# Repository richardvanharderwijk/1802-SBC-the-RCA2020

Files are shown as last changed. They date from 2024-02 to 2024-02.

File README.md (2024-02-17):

This project is the design of a small microcomputer system based on the RCA 1802 COSMAC CPU. 

The specifications of the system are:

• RCA 1802 CPU; 8 bit; up to 3,2 MHz clockspeed

• 64 kB RAM memory

• 8kBROM

• OS(ish): Utility to save, load, start programs; and examine registers and memory

• TTY serial terminal connection, software UART

• 8 bit parallel in/out

• I2C interface; and a clock/calender unit

• All signals available via connectors

• Single 5V via USB port

The design includes a PCB of 10 x 13 cm; and a build and test protocol per unit to facilitate error finding during build.

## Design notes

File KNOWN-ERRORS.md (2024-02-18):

RCA 2020 known errors

1) Error in connection U12 (pin 10, 20 switched) (First in Mk1)
Critical - Open

Switched U12 Vcc and Gnd pins (10, 20). Disadvantage of being own QC.

Workaround: swap with wires, see photo in design, build and test doc.

RfC: correct in next version

2) J5 has no opening in solder mask (First in Mk1)
Critical - Open

The connector with the three pins (J5), the supplier has delivered a wrong footpath. No opening.

Workaround: ask pcb supplier to correct (for me PCBWay’s QC flagged it and corrected it) (add both side solder mask opening for pins and make them plated)

Workaround: quick correction of gerber files without correcting in KiCad masters

RfC: correct in next version

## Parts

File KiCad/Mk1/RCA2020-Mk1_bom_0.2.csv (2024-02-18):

Component | Description | Part | References | Value | Footprint | Quantity Per PCB | Power | Datasheet
1 | Unpolarized capacitor | C | C10 | 20pF | C_Disc_D3.8mm_W2.6mm_P2.50mm | 1 |  | ~
2 | Unpolarized capacitor | C | C2 C3 | 47pF | C_Disc_D3.8mm_W2.6mm_P2.50mm | 2 |  | ~
3 | Polarized capacitor | CP | C1 | 10uF | CP_Radial_D6.3mm_P2.50mm | 1 |  | ~
4 | Polarized capacitor | CP | C4 | 1,5uF | CP_Radial_D5.0mm_P2.00mm | 1 |  | ~
5 | Polarized capacitor | CP | C5 C6 C7 C8 C9 C11 C12 C13 C14 C15 C16 | 0,22uF | CP_Radial_D5.0mm_P2.00mm | 11 |  | ~
6 | Audio Jack, 3 Poles (Stereo / TRS) | AudioJack3 | J5 | AudioJack3 | Lumberg-1501_04-MFG | 1 |  | ~
7 | Generic connector, single row, 01x40, script generated (kicad-library-utils/schlib/autogen/connector/) | Conn_01x40_Female | J1 J4 | Conn_01x40_Female | PinSocket_1x40_P2.54mm_Vertical | 2 |  | ~
8 | Generic screw terminal, single row, 01x02, script generated (kicad-library-utils/schlib/autogen/connector/) | Screw_Terminal_01x02 | J3 | Screw_Terminal_01x02 | TerminalBlock_bornier-2_P5.08mm | 1 |  | ~
9 | USB Type B connector | USB_B | J2 | USB_B | USB_B_OST_USB-B1HSxx_Horizontal | 1 |  | ~
10 | Jumper, 2-pole, closed/bridged | Jumper_2_Bridged | JP1 JP4 JP5 | Jumper_2_Bridged | PinSocket_1x02_P2.54mm_Vertical | 3 |  | ~
11 | Jumper, 2-pole, open | Jumper_2_Open | JP6 JP7 JP8 | Jumper_2_Open | PinSocket_1x02_P2.54mm_Vertical | 3 |  | ~
12 | Jumper, 3-pole, pins 1+2 closed/bridged | Jumper_3_Bridged12 | JP2 JP3 | Jumper_3_Bridged12 | PinSocket_1x03_P2.54mm_Vertical | 2 |  | ~
13 | Resistor | R | R9 R10 | 4k7 | R_Axial_DIN0207_L6.3mm_D2.5mm_P10.16mm_Horizontal | 2 | 0,010638298 | ~
14 | Resistor | R | R3 R4 R5 R6 R7 R8 R11 | 47k | R_Axial_DIN0207_L6.3mm_D2.5mm_P10.16mm_Horizontal | 7 | 0,003723404 | ~
15 | Resistor | R | R1 | 100k | R_Axial_DIN0207_L6.3mm_D2.5mm_P10.16mm_Horizontal | 1 |  | ~
16 | Resistor | R | R2 | 6,8M | R_Axial_DIN0207_L6.3mm_D2.5mm_P10.16mm_Horizontal | 1 |  | ~
17 | 4 resistor network, star topology, bussed resistors, small symbol | R_Network04 | RN1 RN2 | 4x47k | R_Array_SIP5 | 2 | 0,003723404 | http://www.vishay.com/docs/31509/csc.pdf
18 | Push button switch, generic, two pins | SW_Push | SW1 | SW_Push | RAFI_KeySwitch | 1 |  | ~
19 | Paged Parallel EEPROM 64Kb (8K x 8), DIP-28/SOIC-28 | 28C64 | U5 | 28C64 | DIP-28_W15.24mm_Socket | 1 | 0,15 | Atmel
20 | Quad Nor 2 inputs | 4001 | U3 | 4001 | DIP-14_W7.62mm_Socket | 1 |  | http://www.intersil.com/content/dam/Intersil/documents/cd40/cd4000bms-01bms-02bms-25bms.pdf
21 | Quad Nand 2 inputs | 4011 | U15 | 4011 | DIP-14_W7.62mm_Socket | 1 |  | http://www.intersil.com/content/dam/Intersil/documents/cd40/cd4011bms-12bms-23bms.pdf
22 | Triple Nand 3 inputs | 4023 | U11 | 4023 | DIP-14_W7.62mm_Socket | 1 |  | http://www.intersil.com/content/dam/Intersil/documents/cd40/cd4011bms-12bms-23bms.pdf
23 | Triple Nor 3 inputs | 4025 | U6 | 4025 | DIP-14_W7.62mm_Socket | 1 |  | http://www.intersil.com/content/dam/Intersil/documents/cd40/cd4000bms-01bms-02bms-25bms.pdf
24 | Decoder 4 to 10 lines | 4028 | U10 | 4028 | DIP-16_W7.62mm_Socket | 1 | 0,0025 | http://www.intersil.com/content/dam/Intersil/documents/cd40/cd4028bms.pdf
25 |  | 4042 | U7 U8 | 4042 | DIP-16_W7.62mm_Socket | 2
26 | Hex Buffer Inverter | 4049 | U9 | 4049 | DIP-16_W7.62mm_Socket | 1 |  | http://www.intersil.com/content/dam/intersil/documents/cd40/cd4049ubms.pdf
27 | 128K x 8 High-Speed CMOS Static RAM, 55/70ns, DIP-32/SSOP-32 | 628128_DIP32_SSOP32 | U4 | 628128_DIP32_SSOP32 | DIP-32_W15.24mm_Socket | 1 | 0,175 | http://www.futurlec.com/Datasheet/Memory/628128.pdf
28 | 8-bit Buffer/Line Driver 3-state | 74HCT244 | U12 | 74HCT244 | DIP-20_W7.62mm_Socket | 1 | 0,0025 | https://assets.nexperia.com/documents/data-sheet/74HC_HCT244.pdf
29 | 8-bit Latch 3-state outputs | 74LS573 | U13 | 74LS573 | DIP-20_W7.62mm_Socket | 1 |  | 74xx/74hc573.pdf
30 |  | 74LVC4245AD | U14 | 74LVC4245AD | SOP-24_7.5x15.4mm_P1.27mm | 1 | 0,032
31 | 8-bit, General Purpose, 5V, 3.2 MHz, DIP-40 | CDP1802ACE | U1 | CDP1802ACE | DIP-40_W15.24mm | 1 | 0,004 | http://www.cosmacelf.com/publications/data-sheets/cdp1802.pdf
32 | Positive 100mA 30V Linear Regulator, Fixed Output 3.3V, TO-92 | L78L33_TO92 | U2 | L78L33_TO92 | TO-92_Inline | 1 |  | http://www.st.com/content/ccc/resource/technical/document/datasheet/15/55/e5/aa/23/5b/43/fd/CD00000446.pdf/files/CD00000446.pdf/jcr:content/translations/en.CD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
33 |  | PCA9564PW | U16 | PCA9564PW | SO-20_12.8x7.5mm_P1.27mm | 1 | 0,0198
34 | Realtime Clock/Calendar I2C Interface, SOIC-8 | PCF8563T | U17 | PCF8563T | SOIC-8_3.9x4.9mm_P1.27mm | 1 | 0,0033 | https://assets.nexperia.com/documents/data-sheet/PCF8563.pdf
35 | Two pin crystal | Crystal | Y2 | 32.768 kHz | Crystal_Round_D3.0mm_Vertical | 1 |  | ~
36 | Two pin crystal | Crystal | Y1 | Crystal | Crystal_HC49-U_Vertical | 1 |  | ~
 |  |  |  |  |  |  | 0,407185106
Component Groups: | 36
Component Count: | 62
Fitted Components: | 62
Number of PCBs: | 1
Total components: | 62
Schematic Version: | 0.2
Schematic Date: | 20-02-2021
PCB Variant: | udefault
BoM Date: | 2021 February 22, Monday 21:50:06
Schematic Source: | RCA2020-Mk1.sch
KiCad Version: | Eeschema (5.1.5-0-10_14)

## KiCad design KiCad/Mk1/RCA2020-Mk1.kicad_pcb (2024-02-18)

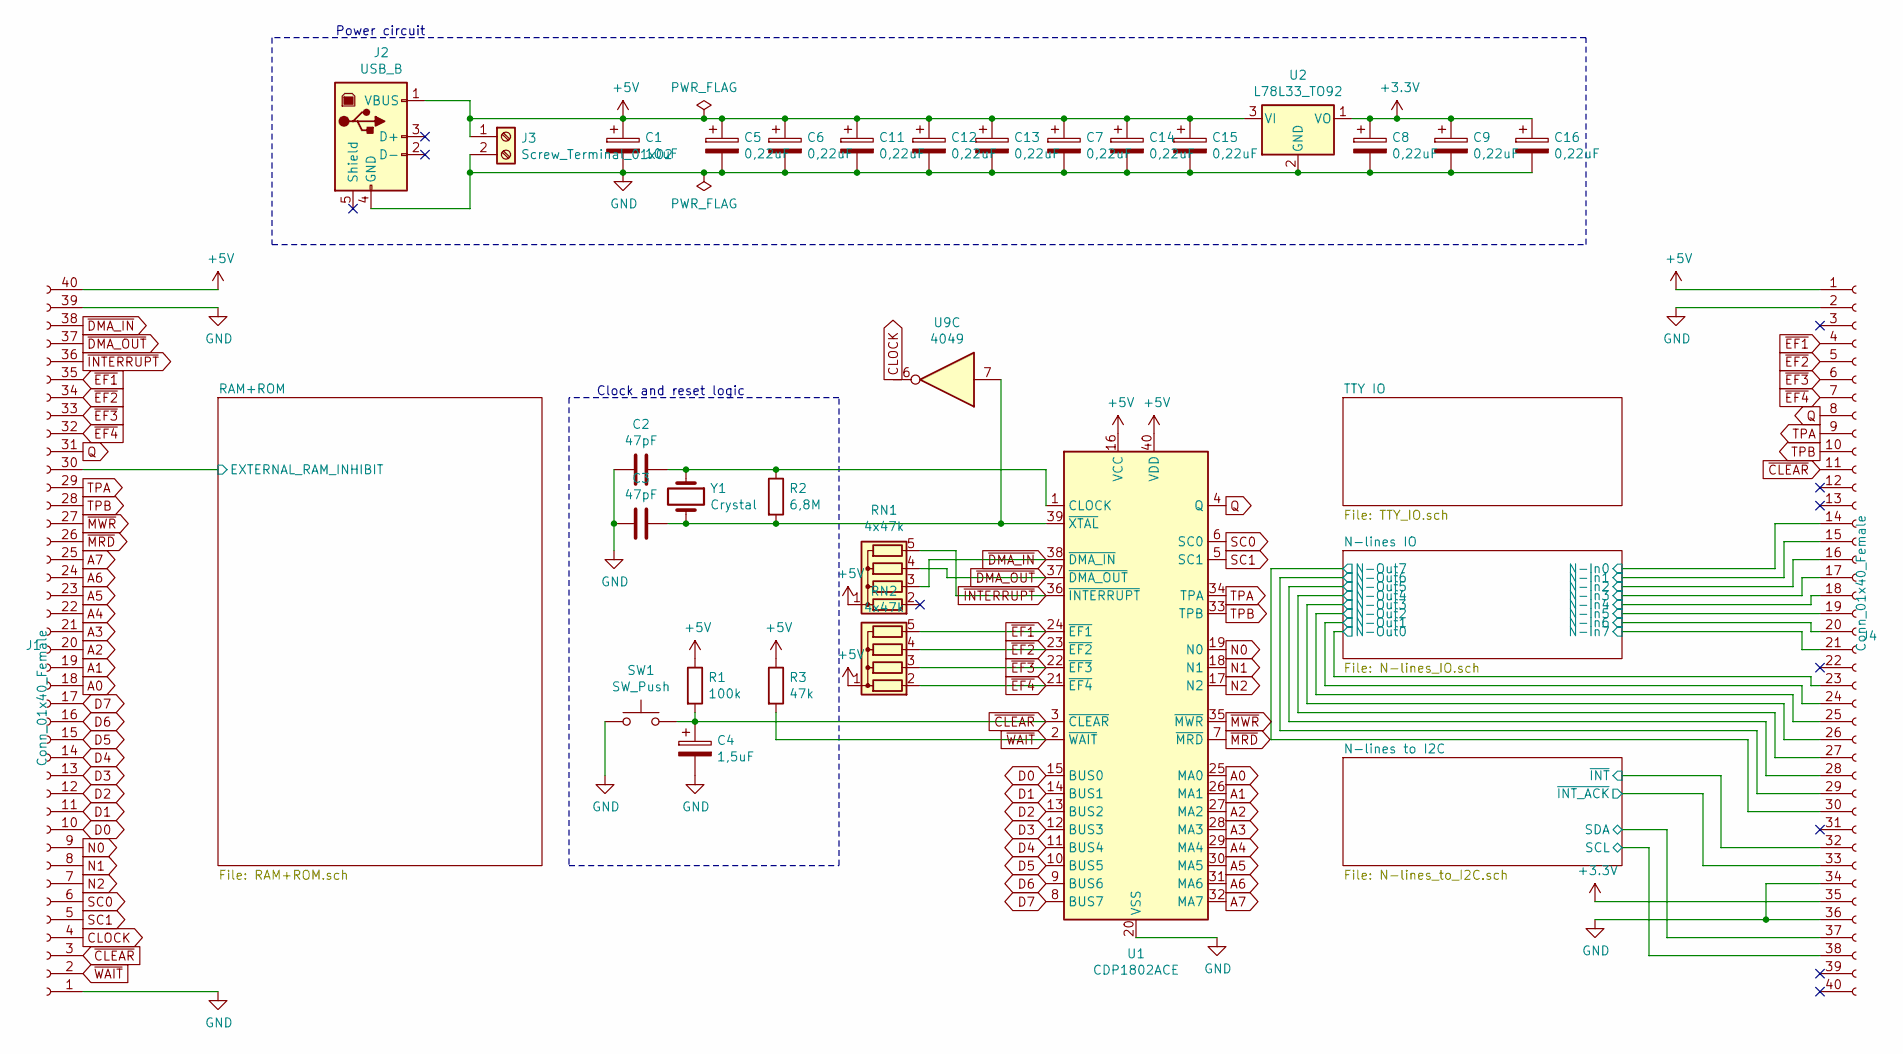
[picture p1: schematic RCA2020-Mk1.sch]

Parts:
C1: 10uF; CP_Radial_D6.3mm_P2.50mm
C2, C3: 47pF; C_Disc_D3.8mm_W2.6mm_P2.50mm
C4: 1,5uF; CP_Radial_D5.0mm_P2.00mm
C5, C6, C7, C8, C9, C11, C12, C13, C14, C15, C16: 0,22uF; CP_Radial_D5.0mm_P2.00mm
J1, J4: Conn_01x40_Female; PinSocket_1x40_P2.54mm_Vertical
J2: USB_B; USB_B_OST_USB-B1HSxx_Horizontal
J3: Screw_Terminal_01x02; TerminalBlock_bornier-2_P5.08mm
R1: 100k; R_Axial_DIN0207_L6.3mm_D2.5mm_P10.16mm_Horizontal
R2: 6,8M; R_Axial_DIN0207_L6.3mm_D2.5mm_P10.16mm_Horizontal
R3: 47k; R_Axial_DIN0207_L6.3mm_D2.5mm_P10.16mm_Horizontal
RN1, RN2: 4x47k; R_Array_SIP5
SW1: SW_Push; RAFI_KeySwitch
U1: CDP1802ACE; DIP-40_W15.24mm
U2: L78L33_TO92; TO-92_Inline
U9: 4049
Y1: Crystal; Crystal_HC49-U_Vertical

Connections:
+3V3: C8.1, C9.1, C16.1, J4.35, U2.1 (VO); also elsewhere on the board
+5V: C1.1, C5.1, C6.1, C7.1, C11.1, C12.1, C13.1, C14.1, C15.1, J1.40, J2.1 (VBUS), J3.1, J4.1, R1.1, R3.1, RN1.1 (common), RN2.1 (common), U1.16 (VCC), U1.40 (VDD), U2.3 (VI); also elsewhere on the board
/N-lines IO/N-In0: J4.14; also elsewhere on the board
/N-lines IO/N-In1: J4.15; also elsewhere on the board
/N-lines IO/N-In2: J4.16; also elsewhere on the board
/N-lines IO/N-In3: J4.17; also elsewhere on the board
/N-lines IO/N-In4: J4.18; also elsewhere on the board
/N-lines IO/N-In5: J4.19; also elsewhere on the board
/N-lines IO/N-In6: J4.20; also elsewhere on the board
/N-lines IO/N-In7: J4.21; also elsewhere on the board
/N-lines IO/N-Out0: J4.23; also elsewhere on the board
/N-lines IO/N-Out1: J4.24; also elsewhere on the board
/N-lines IO/N-Out2: J4.25; also elsewhere on the board
/N-lines IO/N-Out3: J4.26; also elsewhere on the board
/N-lines IO/N-Out4: J4.27; also elsewhere on the board
/N-lines IO/N-Out5: J4.28; also elsewhere on the board
/N-lines IO/N-Out6: J4.29; also elsewhere on the board
/N-lines IO/N-Out7: J4.30; also elsewhere on the board
/N-lines to I2C/SCL: J4.38; also elsewhere on the board
/N-lines to I2C/SDA: J4.37; also elsewhere on the board
/N-lines to I2C/~INT: J4.32; also elsewhere on the board
/N-lines to I2C/~INT_ACK: J4.33; also elsewhere on the board
/RAM+ROM/EXTERNAL_RAM_INHIBIT: J1.30; also elsewhere on the board
A0: J1.18, U1.25 (MA0); also elsewhere on the board
A1: J1.19, U1.26 (MA1); also elsewhere on the board
A2: J1.20, U1.27 (MA2); also elsewhere on the board
A3: J1.21, U1.28 (MA3); also elsewhere on the board
A4: J1.22, U1.29 (MA4); also elsewhere on the board
A5: J1.23, U1.30 (MA5); also elsewhere on the board
A6: J1.24, U1.31 (MA6); also elsewhere on the board
A7: J1.25, U1.32 (MA7); also elsewhere on the board
CLOCK: J1.4, U9.6
D0: J1.10, U1.15 (BUS0); also elsewhere on the board
D1: J1.11, U1.14 (BUS1); also elsewhere on the board
D2: J1.12, U1.13 (BUS2); also elsewhere on the board
D3: J1.13, U1.12 (BUS3); also elsewhere on the board
D4: J1.14, U1.11 (BUS4); also elsewhere on the board
D5: J1.15, U1.10 (BUS5); also elsewhere on the board
D6: J1.16, U1.9 (BUS6); also elsewhere on the board
D7: J1.17, U1.8 (BUS7); also elsewhere on the board
GND: C1.2, C2.2, C3.2, C4.2, C5.2, C6.2, C7.2, C8.2, C9.2, C11.2, C12.2, C13.2, C14.2, C15.2, C16.2, J1.1, J1.39, J2.4 (GND), J3.2, J4.2, J4.34, J4.36, SW1.1, U1.20 (VSS), U2.2 (GND); also elsewhere on the board
N0: J1.9, U1.19 (N0); also elsewhere on the board
N1: J1.8, U1.18 (N1); also elsewhere on the board
N2: J1.7, U1.17 (N2); also elsewhere on the board
unnamed: C2.1, R2.1, U1.1 (CLOCK), Y1.1
unnamed: C3.1, R2.2, U1.39 (~XTAL), U9.7, Y1.2
Q: J1.31, J4.8, U1.4 (Q); also elsewhere on the board
SC0: J1.6, U1.6 (SC0); also elsewhere on the board
SC1: J1.5, U1.5 (SC1); also elsewhere on the board
TPA: J1.29, J4.9, U1.34 (TPA); also elsewhere on the board
TPB: J1.28, J4.10, U1.33 (TPB); also elsewhere on the board
~CLEAR: C4.1, J1.3, J4.11, R1.2, SW1.2, U1.3 (~CLEAR); also elsewhere on the board
~DMA_IN: J1.38, RN1.3 (R2), U1.38 (~DMA_IN)
~DMA_OUT: J1.37, RN1.4 (R3), U1.37 (~DMA_OUT)
~EF1: J1.35, J4.4, RN2.5 (R4), U1.24 (~EF1)
~EF2: J1.34, J4.5, RN2.4 (R3), U1.23 (~EF2)
~EF3: J1.33, J4.6, RN2.3 (R2), U1.22 (~EF3)
~EF4: J1.32, J4.7, RN2.2 (R1), U1.21 (~EF4); also elsewhere on the board
~INTERRUPT: J1.36, RN1.5 (R4), U1.36 (~INTERRUPT); also elsewhere on the board
~MRD: J1.26, U1.7 (~MRD); also elsewhere on the board
~MWR: J1.27, U1.35 (~MWR); also elsewhere on the board
~WAIT: J1.2, R3.2, U1.2 (~WAIT); also elsewhere on the board

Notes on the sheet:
Clock and reset logic
Power circuit

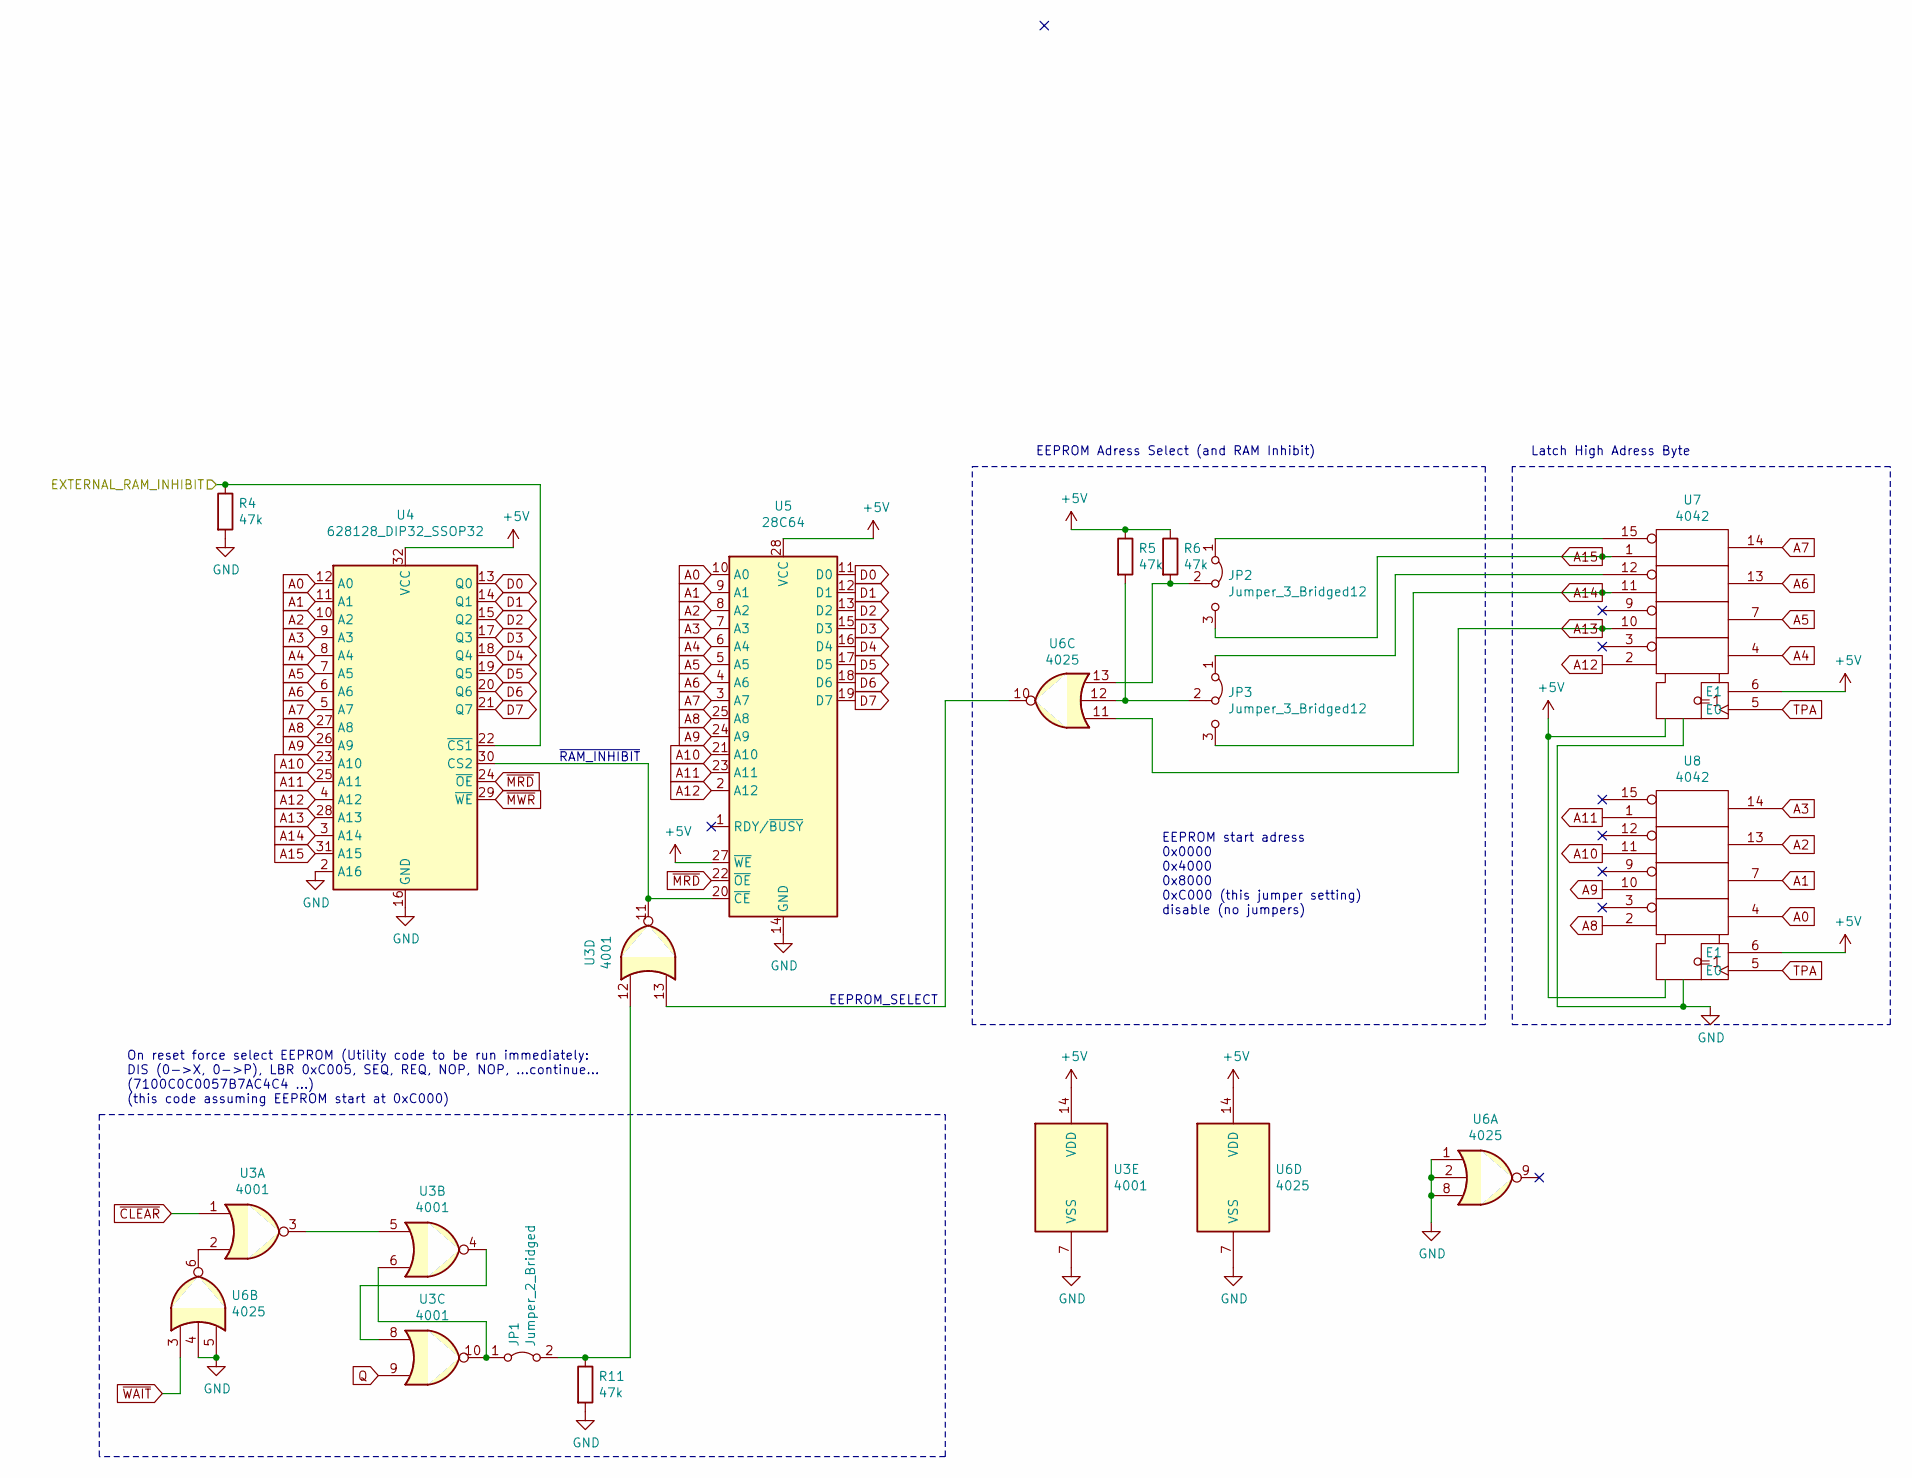
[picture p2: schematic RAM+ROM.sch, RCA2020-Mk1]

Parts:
JP1: Jumper_2_Bridged; PinSocket_1x02_P2.54mm_Vertical
JP2, JP3: Jumper_3_Bridged12; PinSocket_1x03_P2.54mm_Vertical
R4, R5, R6, R11: 47k; R_Axial_DIN0207_L6.3mm_D2.5mm_P10.16mm_Horizontal
U3: 4001; DIP-14_W7.62mm_Socket
U4: 628128_DIP32_SSOP32; DIP-32_W15.24mm_Socket
U5: 28C64; DIP-28_W15.24mm_Socket
U6: 4025; DIP-14_W7.62mm_Socket
U7, U8: 4042; DIP-16_W7.62mm_Socket

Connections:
+5V: R5.1, R6.1, U3.14 (VDD), U4.32 (VCC), U5.27 (~WE), U5.28 (VCC), U6.14 (VDD), U7.6 (E1), U7.16 (Vdd), U8.6 (E1), U8.16 (Vdd); also elsewhere on the board
/RAM+ROM/EXTERNAL_RAM_INHIBIT: R4.1, U4.22 (~CS1); also elsewhere on the board
A0: U4.12 (A0), U5.10 (A0), U8.4; also elsewhere on the board
A1: U4.11 (A1), U5.9 (A1), U8.7; also elsewhere on the board
A2: U4.10 (A2), U5.8 (A2), U8.13; also elsewhere on the board
A3: U4.9 (A3), U5.7 (A3), U8.14; also elsewhere on the board
A4: U4.8 (A4), U5.6 (A4), U7.4; also elsewhere on the board
A5: U4.7 (A5), U5.5 (A5), U7.7; also elsewhere on the board
A6: U4.6 (A6), U5.4 (A6), U7.13; also elsewhere on the board
A7: U4.5 (A7), U5.3 (A7), U7.14; also elsewhere on the board
A8: U4.27 (A8), U5.25 (A8), U8.2
A9: U4.26 (A9), U5.24 (A9), U8.10
A10: U4.23 (A10), U5.21 (A10), U8.11
A11: U4.25 (A11), U5.23 (A11), U8.1
A12: U4.4 (A12), U5.2 (A12), U7.2
A13: U4.28 (A13), U6.11, U7.10
A14: JP3.3 (B), U4.3 (A14), U7.11
A15: JP2.3 (B), U4.31 (A15), U7.1
D0: U4.13 (Q0), U5.11 (D0); also elsewhere on the board
D1: U4.14 (Q1), U5.12 (D1); also elsewhere on the board
D2: U4.15 (Q2), U5.13 (D2); also elsewhere on the board
D3: U4.17 (Q3), U5.15 (D3); also elsewhere on the board
D4: U4.18 (Q4), U5.16 (D4); also elsewhere on the board
D5: U4.19 (Q5), U5.17 (D5); also elsewhere on the board
D6: U4.20 (Q6), U5.18 (D6); also elsewhere on the board
D7: U4.21 (Q7), U5.19 (D7); also elsewhere on the board
GND: R4.2, R11.2, U3.7 (VSS), U4.2 (A16), U4.16 (GND), U5.14 (GND), U6.1, U6.2, U6.4, U6.5, U6.7 (VSS), U6.8, U7.8 (Vss), U8.8 (Vss); also elsewhere on the board
unnamed: JP1.1 (A), U3.6, U3.10
unnamed: JP1.2 (B), R11.1, U3.12
unnamed: JP2.1 (A), U7.15
unnamed: JP2.2 (C), R6.2, U6.13
unnamed: JP3.1 (A), U7.12
unnamed: JP3.2 (C), R5.2, U6.12
unnamed: U3.2, U6.6
unnamed: U3.3, U3.5
unnamed: U3.4, U3.8
unnamed: U3.11, U4.30 (CS2), U5.20 (~CE)
unnamed: U3.13, U6.10
Q: U3.9; also elsewhere on the board
TPA: U7.5 (E0), U8.5 (E0); also elsewhere on the board
~CLEAR: U3.1; also elsewhere on the board
~MRD: U4.24 (~OE), U5.22 (~OE); also elsewhere on the board
~MWR: U4.29 (~WE); also elsewhere on the board
~WAIT: U6.3; also elsewhere on the board

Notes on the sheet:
EEPROM_SELECT
~RAM_INHIBIT
Latch High Adress Byte
EEPROM Adress Select (and RAM Inhibit)
On reset force select EEPROM (Utility code to be run immediately: DIS (0->X, 0->P), LBR 0xC005, SEQ, REQ, NOP, NOP, …continue… (7100C0C0057B7AC4C4 …) (this code assuming EEPROM start at 0xC000)
EEPROM start adress 0x0000 0x4000 0x8000 0xC000 (this jumper setting) disable (no jumpers)

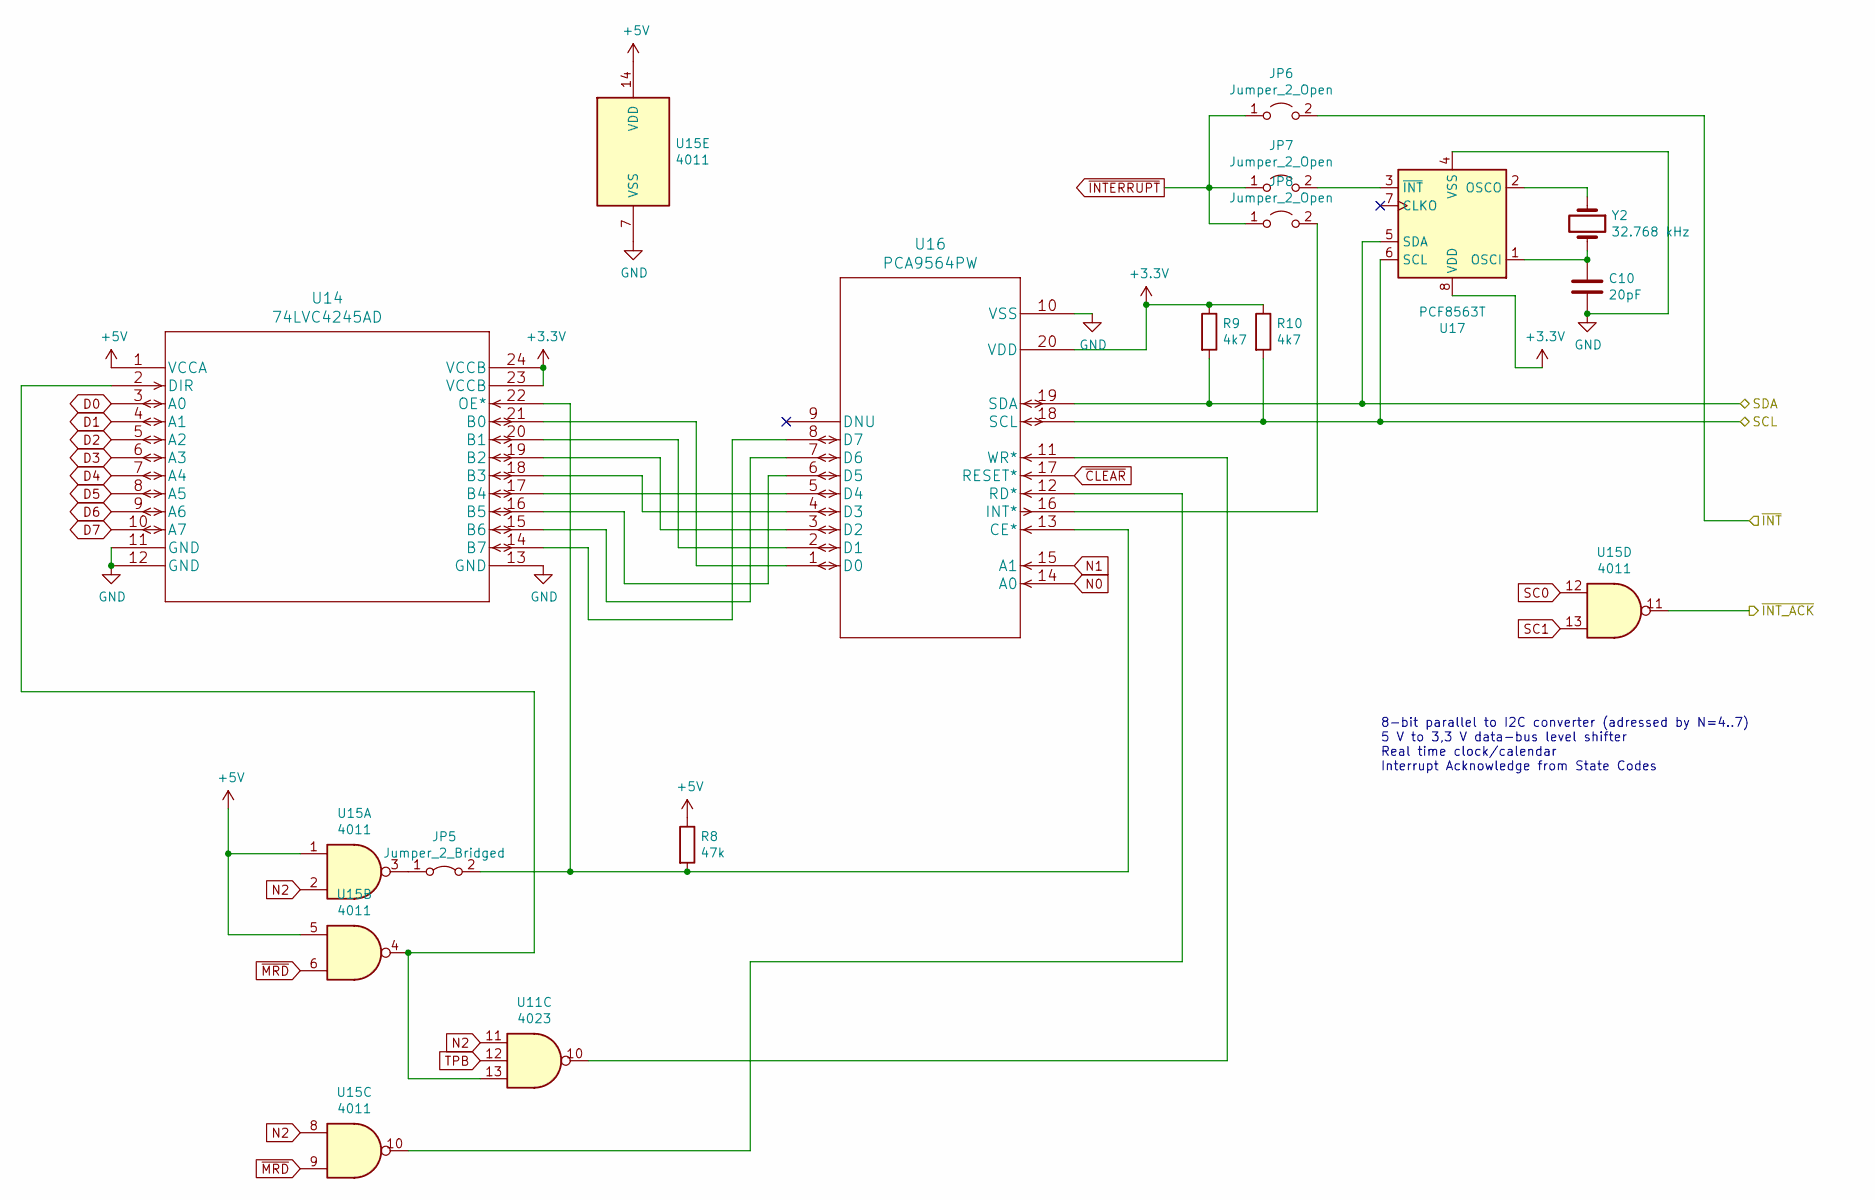
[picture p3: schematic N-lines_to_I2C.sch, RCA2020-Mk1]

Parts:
C10: 20pF; C_Disc_D3.8mm_W2.6mm_P2.50mm
JP5: Jumper_2_Bridged; PinSocket_1x02_P2.54mm_Vertical
JP6, JP7, JP8: Jumper_2_Open; PinSocket_1x02_P2.54mm_Vertical
R8: 47k; R_Axial_DIN0207_L6.3mm_D2.5mm_P10.16mm_Horizontal
R9, R10: 4k7; R_Axial_DIN0207_L6.3mm_D2.5mm_P10.16mm_Horizontal
U11: 4023; DIP-14_W7.62mm_Socket
U14: 74LVC4245AD; SOP-24_7.5x15.4mm_P1.27mm
U15: 4011; DIP-14_W7.62mm_Socket
U16: PCA9564PW; SO-20_12.8x7.5mm_P1.27mm
U17: PCF8563T; SOIC-8_3.9x4.9mm_P1.27mm
Y2: 32.768 kHz; Crystal_Round_D3.0mm_Vertical

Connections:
+3V3: R9.1, R10.1, U14.23 (VCCB), U14.24 (VCCB), U16.20 (VDD), U17.8 (VDD); also elsewhere on the board
+5V: R8.1, U14.1 (VCCA), U15.1, U15.5, U15.14 (VDD); also elsewhere on the board
/N-lines to I2C/SCL: R10.2, U16.18 (SCL), U17.6 (SCL); also elsewhere on the board
/N-lines to I2C/SDA: R9.2, U16.19 (SDA), U17.5 (SDA); also elsewhere on the board
/N-lines to I2C/~INT: JP6.2 (B); also elsewhere on the board
/N-lines to I2C/~INT_ACK: U15.11; also elsewhere on the board
D0: U14.3 (A0); also elsewhere on the board
D1: U14.4 (A1); also elsewhere on the board
D2: U14.5 (A2); also elsewhere on the board
D3: U14.6 (A3); also elsewhere on the board
D4: U14.7 (A4); also elsewhere on the board
D5: U14.8 (A5); also elsewhere on the board
D6: U14.9 (A6); also elsewhere on the board
D7: U14.10 (A7); also elsewhere on the board
GND: C10.2, U14.11 (GND), U14.12 (GND), U14.13 (GND), U15.7 (VSS), U16.10 (VSS), U17.4 (VSS); also elsewhere on the board
N0: U16.14 (A0); also elsewhere on the board
N1: U16.15 (A1); also elsewhere on the board
N2: U11.11, U15.2, U15.8; also elsewhere on the board
unnamed: C10.1, U17.1 (OSCI), Y2.2
unnamed: JP5.1 (A), U15.3
unnamed: JP5.2 (B), R8.2, U14.22 (OE*), U16.13 (CE*)
unnamed: JP7.2 (B), U17.3 (~INT~)
unnamed: JP8.2 (B), U16.16 (INT*)
unnamed: U11.10, U16.11 (WR*)
unnamed: U11.13, U14.2 (DIR), U15.4
unnamed: U14.14 (B7), U16.8 (D7)
unnamed: U14.15 (B6), U16.7 (D6)
unnamed: U14.16 (B5), U16.6 (D5)
unnamed: U14.17 (B4), U16.5 (D4)
unnamed: U14.18 (B3), U16.4 (D3)
unnamed: U14.19 (B2), U16.3 (D2)
unnamed: U14.20 (B1), U16.2 (D1)
unnamed: U14.21 (B0), U16.1 (D0)
unnamed: U15.10, U16.12 (RD*)
unnamed: U17.2 (OSCO), Y2.1
SC0: U15.12; also elsewhere on the board
SC1: U15.13; also elsewhere on the board
TPB: U11.12; also elsewhere on the board
~CLEAR: U16.17 (RESET*); also elsewhere on the board
~INTERRUPT: JP6.1 (A), JP7.1 (A), JP8.1 (A); also elsewhere on the board
~MRD: U15.6, U15.9; also elsewhere on the board

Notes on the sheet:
8-bit parallel to I2C converter (adressed by N=4..7) 5 V to 3,3 V data-bus level shifter Real time clock/calendar Interrupt Acknowledge from State Codes

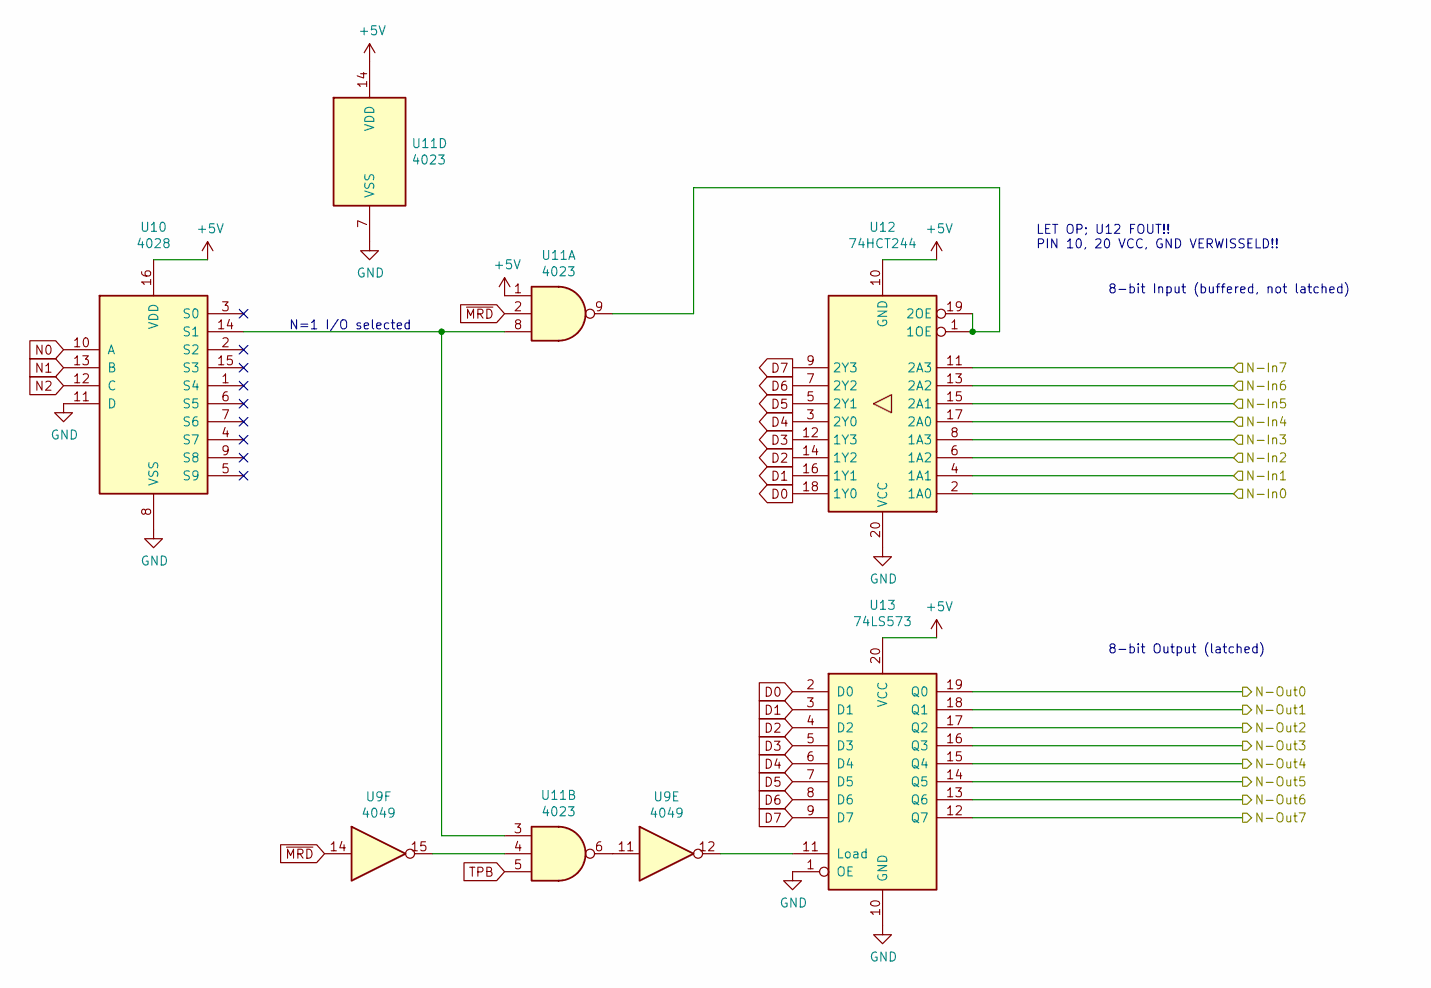
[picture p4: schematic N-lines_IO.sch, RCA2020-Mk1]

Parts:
U9: 4049; DIP-16_W7.62mm_Socket
U10: 4028; DIP-16_W7.62mm_Socket
U11: 4023; DIP-14_W7.62mm_Socket
U12: 74HCT244; DIP-20_W7.62mm_Socket
U13: 74LS573; DIP-20_W7.62mm_Socket

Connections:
+5V: U10.16 (VDD), U11.1, U11.14 (VDD), U12.10 (GND), U13.20 (VCC); also elsewhere on the board
/N-lines IO/N-In0: U12.2 (1A0); also elsewhere on the board
/N-lines IO/N-In1: U12.4 (1A1); also elsewhere on the board
/N-lines IO/N-In2: U12.6 (1A2); also elsewhere on the board
/N-lines IO/N-In3: U12.8 (1A3); also elsewhere on the board
/N-lines IO/N-In4: U12.17 (2A0); also elsewhere on the board
/N-lines IO/N-In5: U12.15 (2A1); also elsewhere on the board
/N-lines IO/N-In6: U12.13 (2A2); also elsewhere on the board
/N-lines IO/N-In7: U12.11 (2A3); also elsewhere on the board
/N-lines IO/N-Out0: U13.19 (Q0); also elsewhere on the board
/N-lines IO/N-Out1: U13.18 (Q1); also elsewhere on the board
/N-lines IO/N-Out2: U13.17 (Q2); also elsewhere on the board
/N-lines IO/N-Out3: U13.16 (Q3); also elsewhere on the board
/N-lines IO/N-Out4: U13.15 (Q4); also elsewhere on the board
/N-lines IO/N-Out5: U13.14 (Q5); also elsewhere on the board
/N-lines IO/N-Out6: U13.13 (Q6); also elsewhere on the board
/N-lines IO/N-Out7: U13.12 (Q7); also elsewhere on the board
D0: U12.18 (1Y0), U13.2 (D0); also elsewhere on the board
D1: U12.16 (1Y1), U13.3 (D1); also elsewhere on the board
D2: U12.14 (1Y2), U13.4 (D2); also elsewhere on the board
D3: U12.12 (1Y3), U13.5 (D3); also elsewhere on the board
D4: U12.3 (2Y0), U13.6 (D4); also elsewhere on the board
D5: U12.5 (2Y1), U13.7 (D5); also elsewhere on the board
D6: U12.7 (2Y2), U13.8 (D6); also elsewhere on the board
D7: U12.9 (2Y3), U13.9 (D7); also elsewhere on the board
GND: U10.8 (VSS), U10.11 (D), U11.7 (VSS), U12.20 (VCC), U13.1 (OE), U13.10 (GND); also elsewhere on the board
N0: U10.10 (A); also elsewhere on the board
N1: U10.13 (B); also elsewhere on the board
N2: U10.12 (C); also elsewhere on the board
unnamed: U10.14 (S1), U11.3, U11.8
unnamed: U9.15, U11.4
unnamed: U9.11, U11.6
unnamed: U11.9, U12.1 (1OE), U12.19 (2OE)
unnamed: U9.12, U13.11 (Load)
TPB: U11.5; also elsewhere on the board
~MRD: U9.14, U11.2; also elsewhere on the board

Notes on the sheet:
8-bit Input (buffered, not latched)
8-bit Output (latched)
N=1 I/O selected
LET OP; U12 FOUT!! PIN 10, 20 VCC, GND VERWISSELD!!

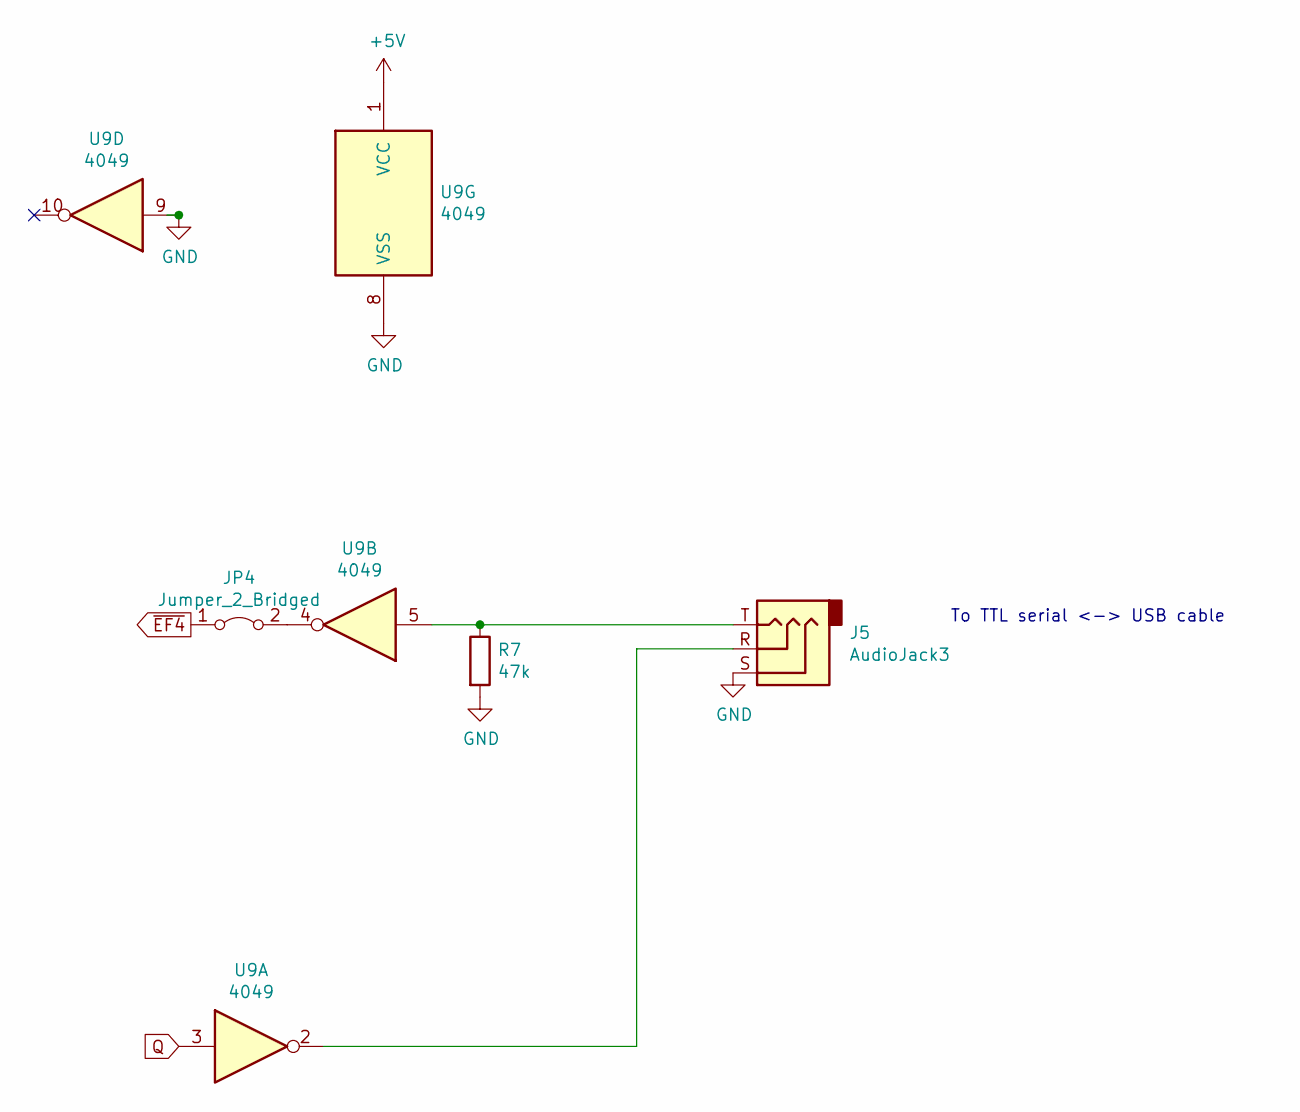
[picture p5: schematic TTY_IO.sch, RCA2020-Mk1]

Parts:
J5: AudioJack3; Lumberg-1501_04-MFG
JP4: Jumper_2_Bridged; PinSocket_1x02_P2.54mm_Vertical
R7: 47k; R_Axial_DIN0207_L6.3mm_D2.5mm_P10.16mm_Horizontal
U9: 4049; DIP-16_W7.62mm_Socket

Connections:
+5V: U9.1 (VCC); also elsewhere on the board
GND: J5.S, R7.2, U9.8 (VSS), U9.9; also elsewhere on the board
unnamed: J5.R, U9.2
unnamed: J5.T, R7.1, U9.5
unnamed: JP4.2 (B), U9.4
Q: U9.3; also elsewhere on the board
~EF4: JP4.1 (A); also elsewhere on the board

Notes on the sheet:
To TTL serial <-> USB cable

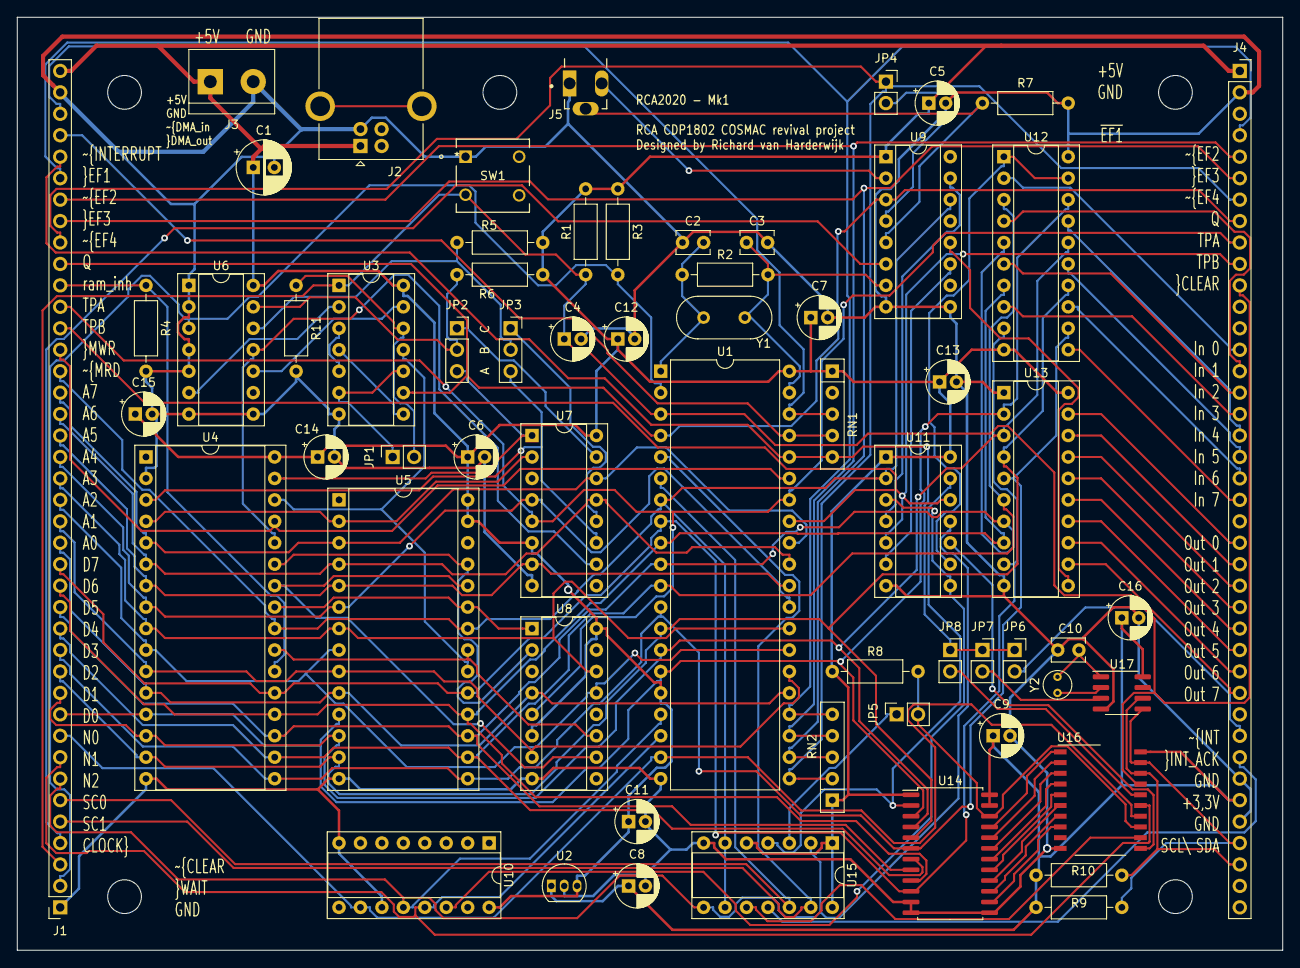
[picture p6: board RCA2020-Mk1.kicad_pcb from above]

Board: 2 copper layers, 149.9 x 110.5 mm, 62 parts (0 on the bottom side), 106 nets.

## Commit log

2024-02-18 KiCad files RCA2020-Mk1
    [N-lines_IO.sch, N-lines_to_I2C.sch, RAM+ROM.sch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]
2024-02-18 RCA2020 Gerbers Mk1
    [RCA2020-Mk1-B_Cu.gbr, RCA2020-Mk1-B_Mask.gbr, RCA2020-Mk1-B_Paste.gbr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]
2024-02-18 RCA2020 KiCad files Mk1
    [N-lines_IO.sch, N-lines_to_I2C.sch, RAM+ROM.sch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]

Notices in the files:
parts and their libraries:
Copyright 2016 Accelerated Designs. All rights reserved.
